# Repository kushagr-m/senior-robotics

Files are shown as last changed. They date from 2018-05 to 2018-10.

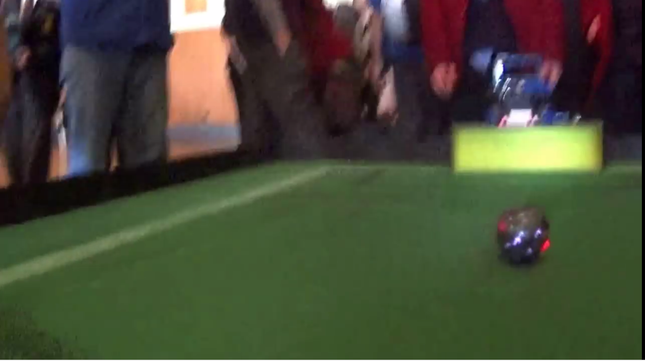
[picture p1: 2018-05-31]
callibyellow.png

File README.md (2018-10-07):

# Nationals
## Roles and Responsibilities:
- **John:** Schematic design, wiring, compass
- **Elvis:** CAD, hardware construction
- **Leon:** Component digitisation, hardware construction, strategy
- **Ben:** Hardware construction, component digitisation
- **Angus:** PCB design, serial communication, strategy
- **Kush:** OpenCV

## Timeline and Plan:
- Work out new plate designs _(Weeks 1-2) (13/08 - 26/08)_
- Work out new components, order and create schematic and PCB _(Weeks 1-4) (13/08 - 01/09)_
- Begin testing of tactics (hardware + software) _(Weeks 2-5) (20/08 - 10/09)_
- Construct robots, test, and finalise _(Weeks 4-7) (03/09 - 30/09)_
- Final optimisation _(Weeks 7-8) (24/09 - 07/10)_
- _2018 Australian Open National Competition: Sat 06/10 - Sun 07/10_

## Competition Times
### Saturday 06/10
- 11:10 Table 12 vs Legolas (Camden Haven High School) - _DRAW (0-0)_
- 12:10 Table 11 vs InfraReady (Private entry) - _LOSS (0-10)_
- 2:10 Table 12 vs Undecided (Camden Haven High School) - _DRAW (0-0)_
- 3:50 Table 12 vs Ambusch (Camden Haven High School) - _LOSS (0-?)_
### Sunday 07/10
- 10:00 Table 12 vs H010n0m1c (Private entry) - _LOSS (0-10)_
- 11:00 Table 12 vs M108 (The Scots College) - _LOSS (1-11)_
- 11:40 Table 12 vs Team APEX (Brisbane Boys College) - _LOSS (0-10)_

## Links
- **[VS Code](https://www.google.com)**: Live collaboration of code for Raspberry Pi and Arduino
- **[Upverter](https://upverter.com/Phobots/f1d2b6a10bcaeffc/Soccer-Bot/)**: Live collaboration of schematic and PCB designs

A note from our sponsors: _Congratulations on being runner up in the state competition, and now entering the national robotics competition!_

A second note from our sponsors: _Thanks for participating, here's a participation reward lmao 💩_

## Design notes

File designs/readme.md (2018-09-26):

## Design Parts ##

**DXF files:**
  - Top Plate
  - Middle Plate
  - Bottom Plate
  - Test screw

**STL files:**
 - Original Designs:
    - Outer Motor mount
    - Innter Motor mounts
    - Camera Mount
    - Dribbler Mount
    
 - Existing Designs used:
    - Wheel Mount
    - Battery Mount

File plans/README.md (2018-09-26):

# National Competition Plans
Please find plans for
- Components
- Schematic and PCB design
- Plate designs
- Other stuff

Please note that Compass Calibration Data values only for T10 at MHS!

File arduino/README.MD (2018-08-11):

# SENDING MOTOR COMMANDS

To communicate with a specific motor: `DIRECTIONspeed`

**for example:**  
`a100` (FL motor at 100% power)  
`b-100` (FR motor at -100% power)

# RECIEVING TOF DATA

TOF: `ToFNumber:Distance`

**for example:**  
`1:234` - ToF sensor 1 measures 234mm

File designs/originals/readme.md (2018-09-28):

## Original Files ##
*The files in here are all the design files in their original format (3D Models in blender, dxf designs in fusion)*
**Files in here:**
- Blender Files (3D Models):
  - Outer Mount
  - Inner Mount
  - Camera Mount
  - Dribbler
  - Visualisation (Bot in 3D)
- Fusion Files (DXF Files):
  - TopPlate
  - MidPlate
  - BotPlate
  - test (Screw holes)

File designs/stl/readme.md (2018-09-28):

## 3D Printable STL files ##

**Files:**
  - Created by Elvis:
    - Outer Mount
    - Inner Mount
    - Camera Mount
    - Dribbler Mount
  - Existing designs:
    - Wheel Mount
    - Battery Mount

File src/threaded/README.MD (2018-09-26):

# VisionProcess
Runs ball detection vision code in its own thread.  
Based on the threading implementation of `imutils`.

# Usage:
```python
from path.to.vision import VisionProcess
vp = VisionProcess().start()

While True: # in the loop
	try: 
		ret, current, queue = vp.read()
		circleCenter, circleRadius = vp.minEnclosing()
		# ...
		# write all code here.
		# ...
	
	except KeyboardInterrupt:
		break

vp.stop()

```
---

## Values:

### `ret`
Is the ball detected?  
Outputs = `True`/`False`  

### `current`
The **current ball position, relative to the center of the frame**   
Outputs = `(x,y)` (is a tuple)  
*x* = `[-160,160]`  
*y* = `[-120,120]`

### `queue`
History of all ball positions  
Outputs a queue.

---

### **NOTE:** The following two values should not be considered reliable.

### `circleCenter`
The **centre of a circle surrounding the ball**   
Outputs = `(x,y)` (is a tuple) 

### `circleRadius`
The **radius of a circle surrounding the ball**  
Outputs a **float**.

---

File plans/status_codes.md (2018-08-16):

## Status Codes of the RGB LEDs on the Raspberry Pi
### Raspberry Pi
- **Red:**
- **Green:**
- **Blue:**
- **Yellow (RG):**
- **Cyan (GB):**
- **Magenta (RB):**
- **White (RGB):**

Note: _If required, we can install another RGB LED for more combinations_

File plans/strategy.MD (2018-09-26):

# Strategy
```
If Ball is in frame 
	If goal is in front *compass*              (45˚ acceptance each side)
	Correct angle to center the ball in frame	
	move forward
		If goal is out of 45˚ acceptance
		Rotate around the ball until goal is in acceptance range
		then forward
	Else
		Move Forward+Right for 1 second
		Turn 90 degrees clockwise
		Move in a counter-clockwise direction 90 degrees around the ball
		Turn 90 degrees clockwise
Else
	Move forward+left for 0.5 seconds
	Rotate counterclockwise 1 revolution
	Move forward+right for 0.5 seconds
	Rotate counterclockwise 1 revolution
	Move backward+right for 0.5 seconds
	Rotate counterclockwise 1 revolution
	Move backward+left for 0.5 seconds
	Rotate counterclockwise 1 revolution

Note:
Revolution and rotation can be approximated through trial and error
```

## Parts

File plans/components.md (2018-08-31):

## Components
- [x] **Raspberry Pi 2 Model B+:** The brains for OpenCV and logic
  - [ ] **Raspberry Pi Camera Board 2:** To see
  - [x] **HMC5883 Digital Compass:** To find angle to goal, communicates over i2c
  - [x] **VL53L0X Time of Flight Sensors:** 4x, to find distance to edges, communicates over i2c
  - [ ] **Momentary Switch:** To detect when ball is in contact with robot when out of camera view
  - [x] **SPST Switch:** To turn off robot, or at least pause the code
  - [x] **Keyes KY-016 3-color LED module:** 2x, for visual status codes (see `/plans/status_codes`)
- [x] **Arduino MEGA R3 2560**: Generates PWM signals to control motor drivers, communicates over serial
  - [x] **L298N Dual H-Bridge Motor Driver:** 2x, uses PWM signals to control voltage to motors, has on board 5V regulator
    - [x] **6V 294RPM Motors:** 4x, To move the robot
    - [ ] **42mm Omdirectional Wheels:** 4x, to enable omnidirectional movement
- [x] **Logic Level Converter:** Enables bidirectional communication over serial, converts 5V and 3.3V into each other for Arduino and Raspberry Pi
- [x] **5V Converter:** Converts battery voltage to stable 5V to power Raspberry Pi
- [x] **Zippy 5000 20C Li-Po Battery 7.4V:** Powers everything

- [ ] **Breadboard:** To connect all i2c devices (if PCB plate cannot)

Note: _Checkboxes are currently being used for schematic component availability purposes_

----
## Schematic and PCB design
_See `/plans` for link to Upverter project, final schematic and PCB designs uploaded when complete_

----
## Other
- Print PCB as plates
- Have a way to turn on and off the robot without a computer
- Have status codes with RGB LEDs (what it is currently doing, errors...)
- Do not have plates in red or colour similar to ball

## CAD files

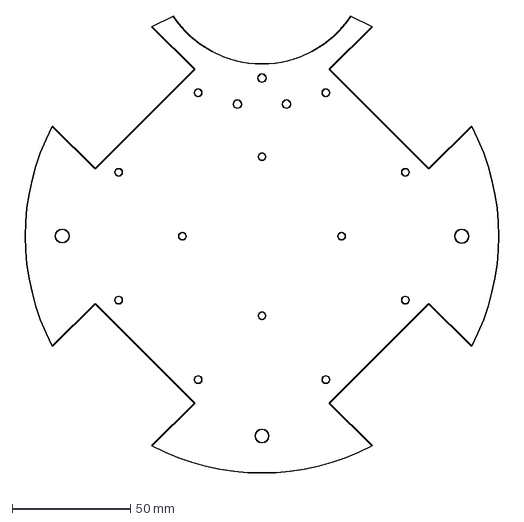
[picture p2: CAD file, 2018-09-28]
designs/dxf/BotPlate.dxf
207.6 x 196.8 mm

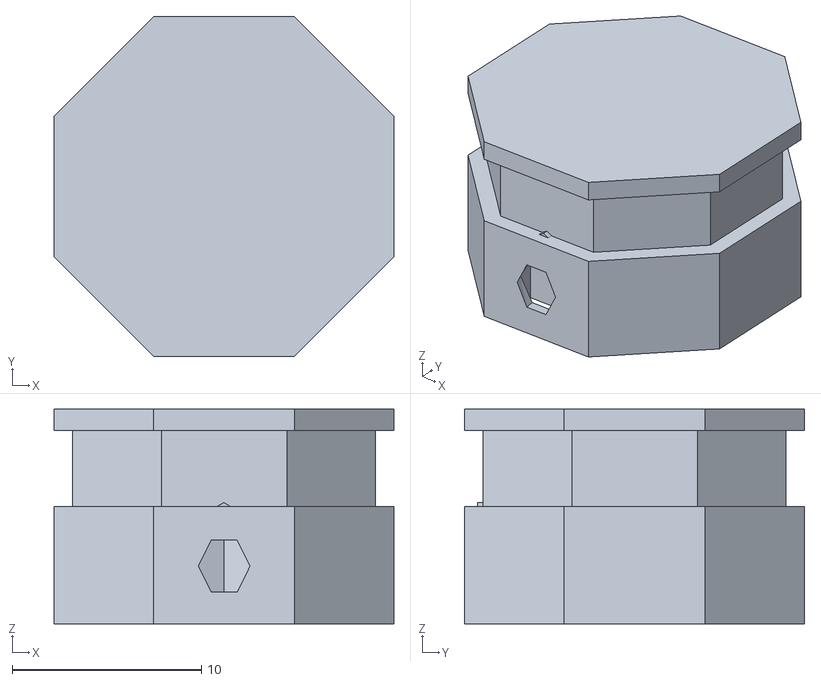
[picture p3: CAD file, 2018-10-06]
designs/stl/DribMotMount.stl
18.0 x 18.0 x 11.4

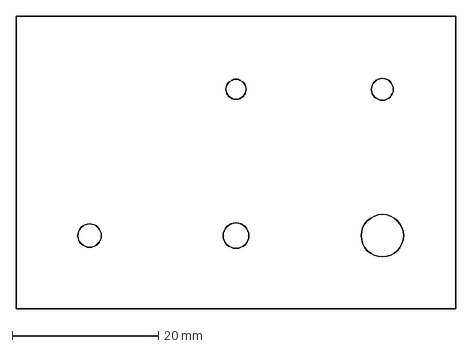
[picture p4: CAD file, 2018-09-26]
designs/dxf/test.dxf
60.0 x 40.0 mm

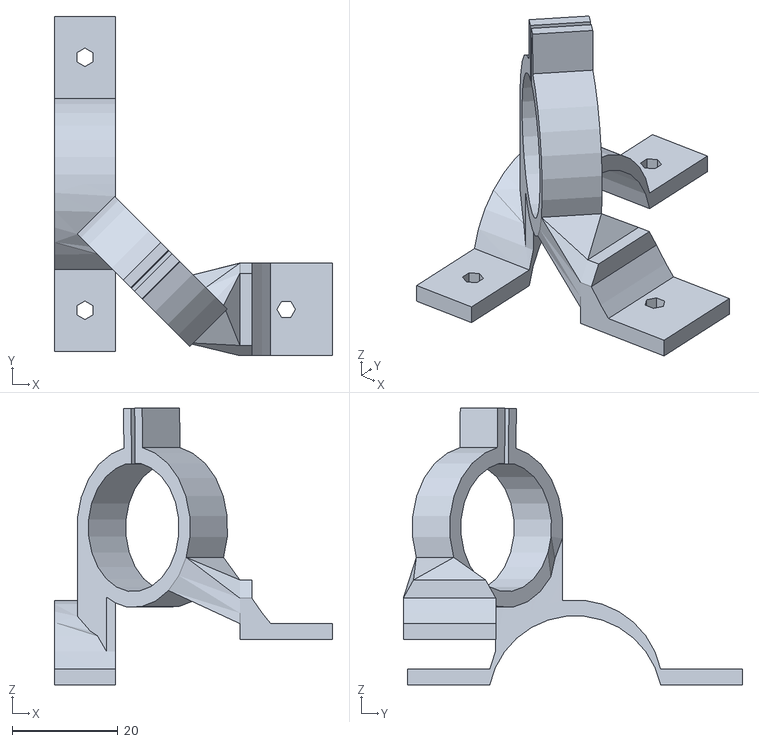
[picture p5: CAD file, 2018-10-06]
designs/stl/Motdrib1.stl
52.5 x 64.1 x 52.3

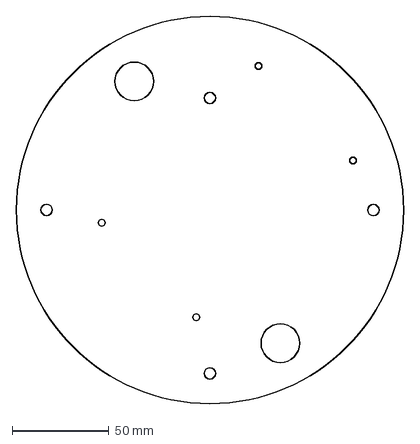
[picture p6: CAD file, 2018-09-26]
designs/dxf/TopPlate.dxf
200.0 x 200.0 mm

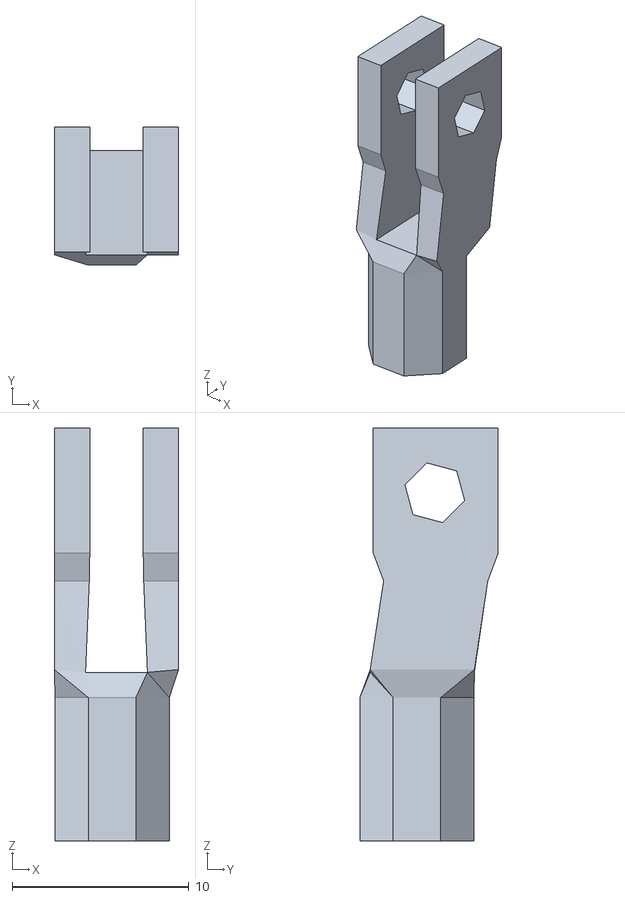
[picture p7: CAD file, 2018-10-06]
designs/stl/RollMount.stl
7.03 x 7.84 x 23.4

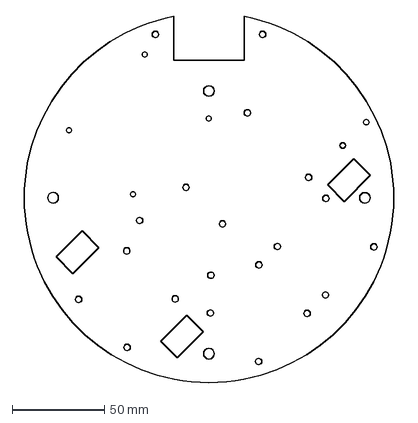
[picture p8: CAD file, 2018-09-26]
designs/dxf/MidPlate.dxf
208.9 x 198.2 mm

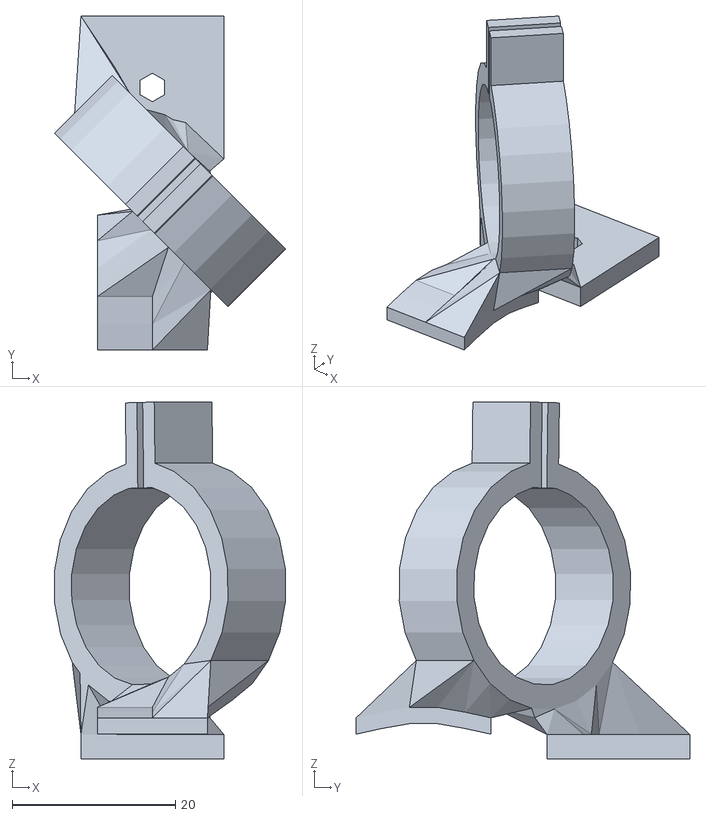
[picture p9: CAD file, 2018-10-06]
designs/stl/Motdrib2.stl
28.3 x 40.9 x 43.7

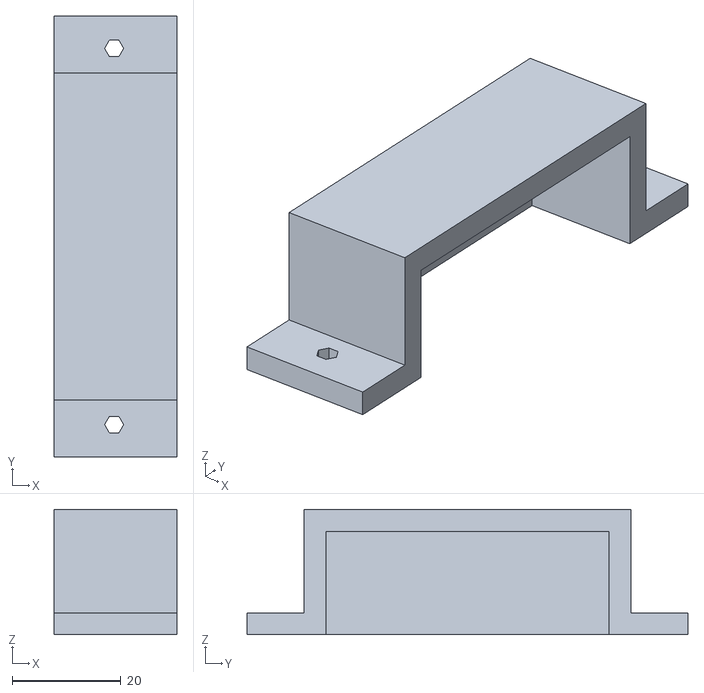
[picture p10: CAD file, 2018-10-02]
designs/stl/BatteryMountPart2.stl
22.5 x 81.0 x 23.0

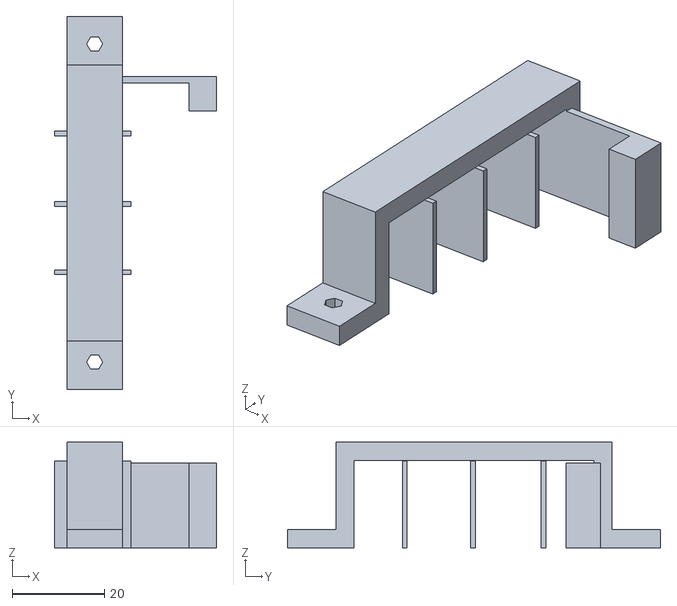
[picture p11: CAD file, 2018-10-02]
designs/stl/BatteryMountPart1.stl
35.2 x 81.0 x 23.0

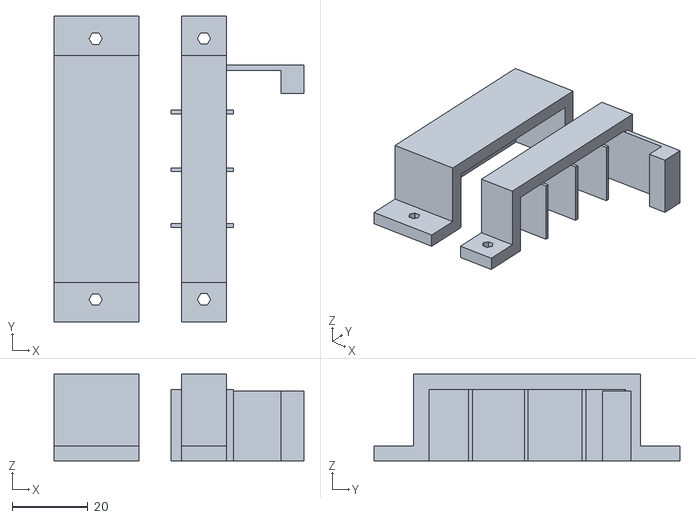
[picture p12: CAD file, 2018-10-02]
designs/stl/BatteryMount.stl
66.1 x 81.0 x 23.0

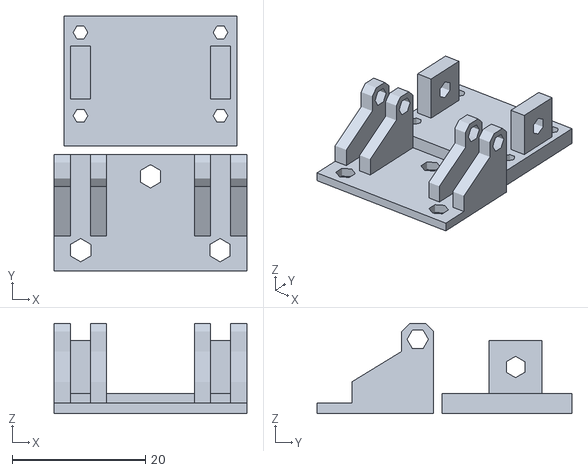
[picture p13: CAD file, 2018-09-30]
designs/stl/CameraMount.stl
28.9 x 38.2 x 13.5

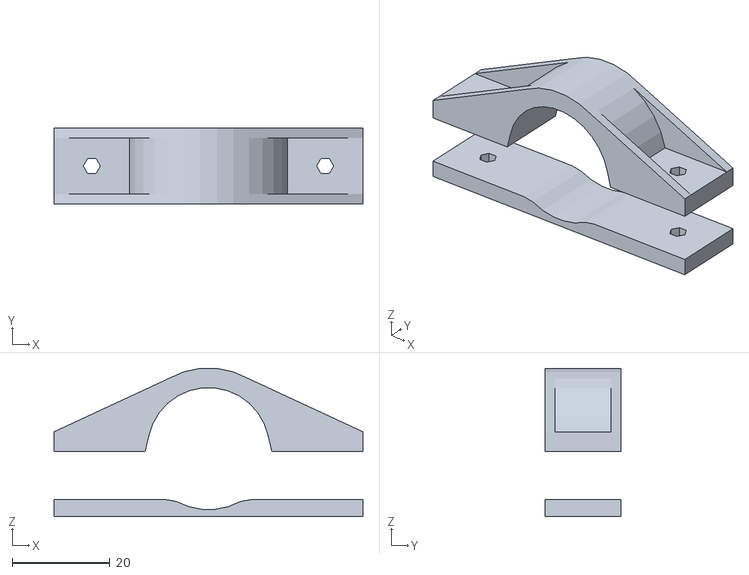
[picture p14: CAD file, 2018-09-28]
designs/stl/OuterMount.stl
63.3 x 15.5 x 30.4

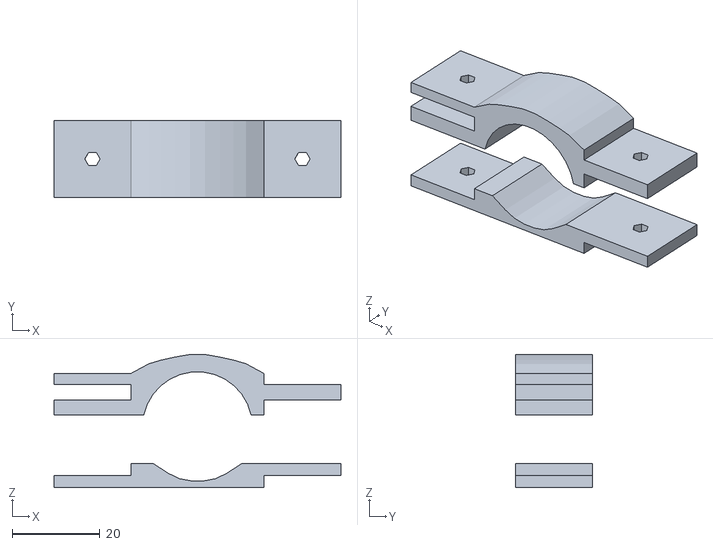
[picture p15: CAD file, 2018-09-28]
designs/stl/InnerMount.stl
65.3 x 17.5 x 30.3

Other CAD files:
designs/stl/WheelMount.stl
designs/originals/Blender Files/Bot Visualisation.blend
designs/originals/Blender Files/Camera Mount.blend
designs/originals/Blender Files/Inner Mount.blend
designs/originals/Blender Files/Outer Mount.blend
designs/originals/Fusion Files/BotPlate.f3d
designs/originals/Fusion Files/MidPlate.f3d
designs/originals/Fusion Files/TopPlate.f3d
designs/originals/Fusion Files/test.f3d

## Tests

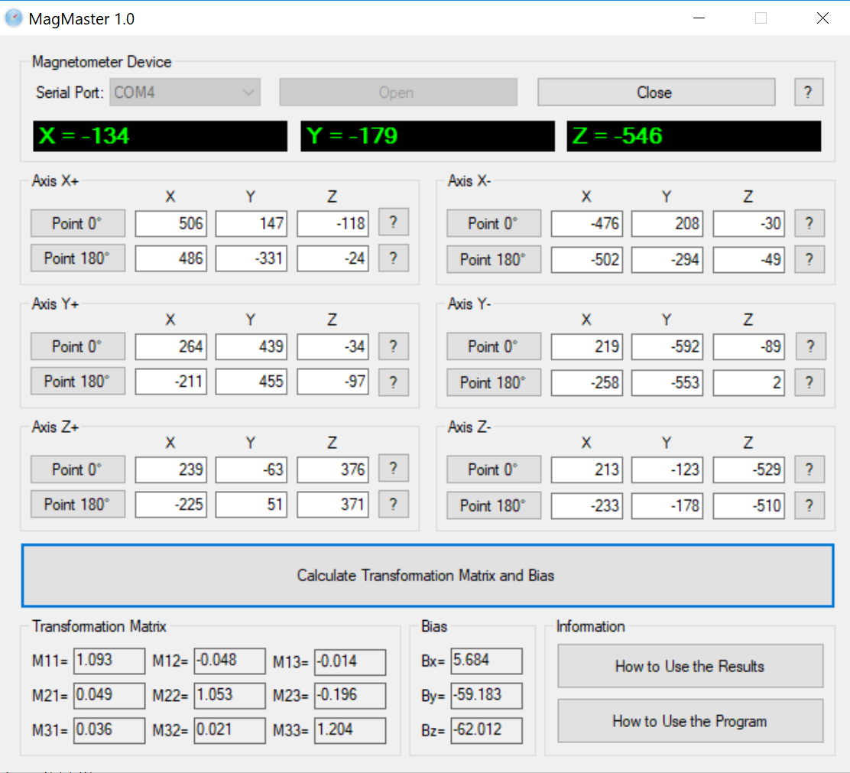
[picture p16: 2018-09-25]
plans/Compass Calibration.png

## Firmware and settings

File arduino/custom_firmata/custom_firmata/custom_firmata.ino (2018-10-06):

/*
  Firmata is a generic protocol for communicating with microcontrollers
  from software on a host computer. It is intended to work with
  any host computer software package.

  To download a host software package, please click on the following link
  to open the list of Firmata client libraries in your default browser.

  https://github.com/firmata/arduino#firmata-client-libraries

  Copyright (C) 2006-2008 Hans-Christoph Steiner.  All rights reserved.
  Copyright (C) 2010-2011 Paul Stoffregen.  All rights reserved.
  Copyright (C) 2009 Shigeru Kobayashi.  All rights reserved.
  Copyright (C) 2009-2016 Jeff Hoefs.  All rights reserved.

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
  See file LICENSE.txt for further informations on licensing terms.

  Last updated August 17th, 2017
*/

#include <Firmata.h>
#include <Adafruit_Sensor.h>
#include <Adafruit_HMC5883_U.h>
#include <Adafruit_SSD1306.h>
#include <Adafruit_GFX.h>

// the minimum interval for sampling analog input
#define MINIMUM_SAMPLING_INTERVAL   1
#define OLED_ADDR   0x3C

Adafruit_SSD1306 display(-1);

#if (SSD1306_LCDHEIGHT != 64)
#error("Height incorrect, please fix Adafruit_SSD1306.h!");
#endif

/*==============================================================================
   GLOBAL VARIABLES
  ============================================================================*/

Adafruit_HMC5883_Unified mag = Adafruit_HMC5883_Unified(12345);

int compass_read()
{
  sensors_event_t event;
  mag.getEvent(&event);
  float heading = atan2(event.magnetic.y, event.magnetic.x);
  float declinationAngle = 0.202749081;
  heading += declinationAngle;
  if (heading < 0)
    heading += 2 * PI;
  if (heading > 2 * PI)
    heading -= 2 * PI;
  float headingDegrees = heading * 180 / M_PI;
  return (int)headingDegrees;
}

#ifdef FIRMATA_SERIAL_FEATURE
SerialFirmata serialFeature;
#endif

/* analog inputs */
int analogInputsToReport = 0; // bitwise array to store pin reporting

/* digital input ports */
byte reportPINs[TOTAL_PORTS];       // 1 = report this port, 0 = silence
byte previousPINs[TOTAL_PORTS];     // previous 8 bits sent

/* pins configuration */
byte portConfigInputs[TOTAL_PORTS]; // each bit: 1 = pin in INPUT, 0 = anything else

/* timer variables */
unsigned long currentMillis;        // store the current value from millis()
unsigned long previousMillis;       // for comparison with currentMillis
unsigned int samplingInterval = 19; // how often to run the main loop (in ms)

boolean isResetting = false;

// Forward declare a few functions to avoid compiler errors with older versions
// of the Arduino IDE.
void setPinModeCallback(byte, int);
void reportAnalogCallback(byte analogPin, int value);
void sysexCallback(byte, byte, byte*);

void outputPort(byte portNumber, byte portValue, byte forceSend)
{
  // pins not configured as INPUT are cleared to zeros
  portValue = portValue & portConfigInputs[portNumber];
  // only send if the value is different than previously sent
  if (forceSend || previousPINs[portNumber] != portValue) {
    Firmata.sendDigitalPort(portNumber, portValue);
    previousPINs[portNumber] = portValue;
  }
}

/* -----------------------------------------------------------------------------
   check all the active digital inputs for change of state, then add any events
   to the Serial output queue using Serial.print() */
void checkDigitalInputs(void)
{
  /* Using non-looping code allows constants to be given to readPort().
     The compiler will apply substantial optimizations if the inputs
     to readPort() are compile-time constants. */
  if (TOTAL_PORTS > 0 && reportPINs[0]) outputPort(0, readPort(0, portConfigInputs[0]), false);
  if (TOTAL_PORTS > 1 && reportPINs[1]) outputPort(1, readPort(1, portConfigInputs[1]), false);
  if (TOTAL_PORTS > 2 && reportPINs[2]) outputPort(2, readPort(2, portConfigInputs[2]), false);
  if (TOTAL_PORTS > 3 && reportPINs[3]) outputPort(3, readPort(3, portConfigInputs[3]), false);
  if (TOTAL_PORTS > 4 && reportPINs[4]) outputPort(4, readPort(4, portConfigInputs[4]), false);
  if (TOTAL_PORTS > 5 && reportPINs[5]) outputPort(5, readPort(5, portConfigInputs[5]), false);
  if (TOTAL_PORTS > 6 && reportPINs[6]) outputPort(6, readPort(6, portConfigInputs[6]), false);
  if (TOTAL_PORTS > 7 && reportPINs[7]) outputPort(7, readPort(7, portConfigInputs[7]), false);
  if (TOTAL_PORTS > 8 && reportPINs[8]) outputPort(8, readPort(8, portConfigInputs[8]), false);
  if (TOTAL_PORTS > 9 && reportPINs[9]) outputPort(9, readPort(9, portConfigInputs[9]), false);
  if (TOTAL_PORTS > 10 && reportPINs[10]) outputPort(10, readPort(10, portConfigInputs[10]), false);
  if (TOTAL_PORTS > 11 && reportPINs[11]) outputPort(11, readPort(11, portConfigInputs[11]), false);
  if (TOTAL_PORTS > 12 && reportPINs[12]) outputPort(12, readPort(12, portConfigInputs[12]), false);
  if (TOTAL_PORTS > 13 && reportPINs[13]) outputPort(13, readPort(13, portConfigInputs[13]), false);
  if (TOTAL_PORTS > 14 && reportPINs[14]) outputPort(14, readPort(14, portConfigInputs[14]), false);
  if (TOTAL_PORTS > 15 && reportPINs[15]) outputPort(15, readPort(15, portConfigInputs[15]), false);
}

// -----------------------------------------------------------------------------
/* sets the pin mode to the correct state and sets the relevant bits in the
   two bit-arrays that track Digital I/O and PWM status
*/
void setPinModeCallback(byte pin, int mode)
{
  if (Firmata.getPinMode(pin) == PIN_MODE_IGNORE)
    return;

  if (IS_PIN_ANALOG(pin)) {
    reportAnalogCallback(PIN_TO_ANALOG(pin), mode == PIN_MODE_ANALOG ? 1 : 0); // turn on/off reporting
  }
  if (IS_PIN_DIGITAL(pin)) {
    if (mode == INPUT || mode == PIN_MODE_PULLUP) {
      portConfigInputs[pin / 8] |= (1 << (pin & 7));
    } else {
      portConfigInputs[pin / 8] &= ~(1 << (pin & 7));
    }
  }
  Firmata.setPinState(pin, 0);
  switch (mode) {
    case PIN_MODE_ANALOG:
      if (IS_PIN_ANALOG(pin)) {
        if (IS_PIN_DIGITAL(pin)) {
          pinMode(PIN_TO_DIGITAL(pin), INPUT);    // disable output driver
#if ARDUINO <= 100
          // deprecated since Arduino 1.0.1 - TODO: drop support in Firmata 2.6
          digitalWrite(PIN_TO_DIGITAL(pin), LOW); // disable internal pull-ups
#endif
        }
        Firmata.setPinMode(pin, PIN_MODE_ANALOG);
      }
      break;
    case INPUT:
      if (IS_PIN_DIGITAL(pin)) {
        pinMode(PIN_TO_DIGITAL(pin), INPUT);    // disable output driver
#if ARDUINO <= 100
        // deprecated since Arduino 1.0.1 - TODO: drop support in Firmata 2.6
        digitalWrite(PIN_TO_DIGITAL(pin), LOW); // disable internal pull-ups
#endif
        Firmata.setPinMode(pin, INPUT);
      }
      break;
    case PIN_MODE_PULLUP:
      if (IS_PIN_DIGITAL(pin)) {
        pinMode(PIN_TO_DIGITAL(pin), INPUT_PULLUP);
        Firmata.setPinMode(pin, PIN_MODE_PULLUP);
        Firmata.setPinState(pin, 1);
      }
      break;
    case OUTPUT:
      if (IS_PIN_DIGITAL(pin)) {
        if (Firmata.getPinMode(pin) == PIN_MODE_PWM) {
          // Disable PWM if pin mode was previously set to PWM.
          digitalWrite(PIN_TO_DIGITAL(pin), LOW);
        }
        pinMode(PIN_TO_DIGITAL(pin), OUTPUT);
        Firmata.setPinMode(pin, OUTPUT);
      }
      break;
    case PIN_MODE_PWM:
      if (IS_PIN_PWM(pin)) {
        pinMode(PIN_TO_PWM(pin), OUTPUT);
        analogWrite(PIN_TO_PWM(pin), 0);
        Firmata.setPinMode(pin, PIN_MODE_PWM);
      }
      break;
    case PIN_MODE_SERIAL:
#ifdef FIRMATA_SERIAL_FEATURE
      serialFeature.handlePinMode(pin, PIN_MODE_SERIAL);
#endif
      break;
    default:
      Firmata.sendString("Unknown pin mode"); // TODO: put error msgs in EEPROM
  }
  // TODO: save status to EEPROM here, if changed
}

/*
   Sets the value of an individual pin. Useful if you want to set a pin value but
   are not tracking the digital port state.
   Can only be used on pins configured as OUTPUT.
   Cannot be used to enable pull-ups on Digital INPUT pins.
*/
void setPinValueCallback(byte pin, int value)
{
  if (pin < TOTAL_PINS && IS_PIN_DIGITAL(pin)) {
    if (Firmata.getPinMode(pin) == OUTPUT) {
      Firmata.setPinState(pin, value);
      digitalWrite(PIN_TO_DIGITAL(pin), value);
    }
  }
}

void analogWriteCallback(byte pin, int value)
{
  if (pin < TOTAL_PINS) {
    switch (Firmata.getPinMode(pin)) {
      case PIN_MODE_PWM:
        if (IS_PIN_PWM(pin))
          analogWrite(PIN_TO_PWM(pin), value);
        Firmata.setPinState(pin, value);
        break;
    }
  }
}

void digitalWriteCallback(byte port, int value)
{
  byte pin, lastPin, pinValue, mask = 1, pinWriteMask = 0;

  if (port < TOTAL_PORTS) {
    // create a mask of the pins on this port that are writable.
    lastPin = port * 8 + 8;
    if (lastPin > TOTAL_PINS) lastPin = TOTAL_PINS;
    for (pin = port * 8; pin < lastPin; pin++) {
      // do not disturb non-digital pins (eg, Rx & Tx)
      if (IS_PIN_DIGITAL(pin)) {
        // do not touch pins in PWM, ANALOG, SERVO or other modes
        if (Firmata.getPinMode(pin) == OUTPUT || Firmata.getPinMode(pin) == INPUT) {
          pinValue = ((byte)value & mask) ? 1 : 0;
          if (Firmata.getPinMode(pin) == OUTPUT) {
            pinWriteMask |= mask;
          } else if (Firmata.getPinMode(pin) == INPUT && pinValue == 1 && Firmata.getPinState(pin) != 1) {
            // only handle INPUT here for backwards compatibility
#if ARDUINO > 100
            pinMode(pin, INPUT_PULLUP);
#else
            // only write to the INPUT pin to enable pullups if Arduino v1.0.0 or earlier
            pinWriteMask |= mask;
#endif
          }
          Firmata.setPinState(pin, pinValue);
        }
      }
      mask = mask << 1;
    }
    writePort(port, (byte)value, pinWriteMask);
  }
}


// -----------------------------------------------------------------------------
/* sets bits in a bit array (int) to toggle the reporting of the analogIns
*/
//void FirmataClass::setAnalogPinReporting(byte pin, byte state) {
//}
void reportAnalogCallback(byte analogPin, int value)
{
  if (analogPin < TOTAL_ANALOG_PINS) {
    if (value == 0) {
      analogInputsToReport = analogInputsToReport & ~ (1 << analogPin);
    } else {
      analogInputsToReport = analogInputsToReport | (1 << analogPin);
      // prevent during system reset or all analog pin values will be reported
      // which may report noise for unconnected analog pins
      if (!isResetting) {
        // Send pin value immediately. This is helpful when connected via
        // ethernet, wi-fi or bluetooth so pin states can be known upon
        // reconnecting.
        Firmata.sendAnalog(analogPin, compass_read());
      }
    }
  }
  // TODO: save status to EEPROM here, if changed
}

void reportDigitalCallback(byte port, int value)
{
  if (port < TOTAL_PORTS) {
    reportPINs[port] = (byte)value;
    // Send port value immediately. This is helpful when connected via
    // ethernet, wi-fi or bluetooth so pin states can be known upon
    // reconnecting.
    if (value) outputPort(port, readPort(port, portConfigInputs[port]), true);
  }
  // do not disable analog reporting on these 8 pins, to allow some
  // pins used for digital, others analog.  Instead, allow both types
  // of reporting to be enabled, but check if the pin is configured
  // as analog when sampling the analog inputs.  Likewise, while
  // scanning digital pins, portConfigInputs will mask off values from any
  // pins configured as analog
}

/*==============================================================================
   SYSEX-BASED commands
  ============================================================================*/

void sysexCallback(byte command, byte argc, byte *argv)
{
  byte mode;
  byte stopTX;
  byte slaveAddress;
  byte data;
  int slaveRegister;
  unsigned int delayTime;

  switch (command) {
    case SAMPLING_INTERVAL:
      if (argc > 1) {
        samplingInterval = argv[0] + (argv[1] << 7);
        if (samplingInterval < MINIMUM_SAMPLING_INTERVAL) {
          samplingInterval = MINIMUM_SAMPLING_INTERVAL;
        }
      } else {
        //Firmata.sendString("Not enough data");
      }
      break;
    case EXTENDED_ANALOG:
      if (argc > 1) {
        int val = argv[1];
        if (argc > 2) val |= (argv[2] << 7);
        if (argc > 3) val |= (argv[3] << 14);
        analogWriteCallback(argv[0], val);
      }
      break;
    case CAPABILITY_QUERY:
      Firmata.write(START_SYSEX);
      Firmata.write(CAPABILITY_RESPONSE);
      for (byte pin = 0; pin < TOTAL_PINS; pin++) {
        if (IS_PIN_DIGITAL(pin)) {
          Firmata.write((byte)INPUT);
          Firmata.write(1);
          Firmata.write((byte)PIN_MODE_PULLUP);
          Firmata.write(1);
          Firmata.write((byte)OUTPUT);
          Firmata.write(1);
        }
        if (IS_PIN_ANALOG(pin)) {
          Firmata.write(PIN_MODE_ANALOG);
          Firmata.write(10); // 10 = 10-bit resolution
        }
        if (IS_PIN_PWM(pin)) {
          Firmata.write(PIN_MODE_PWM);
          Firmata.write(DEFAULT_PWM_RESOLUTION);
        }
#ifdef FIRMATA_SERIAL_FEATURE
        serialFeature.handleCapability(pin);
#endif
        Firmata.write(127);
      }
      Firmata.write(END_SYSEX);
      break;
    case PIN_STATE_QUERY:
      if (argc > 0) {
        byte pin = argv[0];
        Firmata.write(START_SYSEX);
        Firmata.write(PIN_STATE_RESPONSE);
        Firmata.write(pin);
        if (pin < TOTAL_PINS) {
          Firmata.write(Firmata.getPinMode(pin));
          Firmata.write((byte)Firmata.getPinState(pin) & 0x7F);
          if (Firmata.getPinState(pin) & 0xFF80) Firmata.write((byte)(Firmata.getPinState(pin) >> 7) & 0x7F);
          if (Firmata.getPinState(pin) & 0xC000) Firmata.write((byte)(Firmata.getPinState(pin) >> 14) & 0x7F);
        }
        Firmata.write(END_SYSEX);
      }
      break;
    case ANALOG_MAPPING_QUERY:
      Firmata.write(START_SYSEX);
      Firmata.write(ANALOG_MAPPING_RESPONSE);
      for (byte pin = 0; pin < TOTAL_PINS; pin++) {
        Firmata.write(IS_PIN_ANALOG(pin) ? PIN_TO_ANALOG(pin) : 127);
      }
      Firmata.write(END_SYSEX);
      break;

    case SERIAL_MESSAGE:
#ifdef FIRMATA_SERIAL_FEATURE
      serialFeature.handleSysex(command, argc, argv);
#endif
      break;
  }
}

/*==============================================================================
   SETUP()
  ============================================================================*/

void systemResetCallback()
{
  isResetting = true;

  // initialize a defalt state
  // TODO: option to load config from EEPROM instead of default

#ifdef FIRMATA_SERIAL_FEATURE
  serialFeature.reset();
#endif

  for (byte i = 0; i < TOTAL_PORTS; i++) {
    reportPINs[i] = false;    // by default, reporting off
    portConfigInputs[i] = 0;  // until activated
    previousPINs[i] = 0;
  }

  for (byte i = 0; i < TOTAL_PINS; i++) {
    // pins with analog capability default to analog input
    // otherwise, pins default to digital output
    if (IS_PIN_ANALOG(i)) {
      // turns off pullup, configures everything
      setPinModeCallback(i, PIN_MODE_ANALOG);
    } else if (IS_PIN_DIGITAL(i)) {
      // sets the output to 0, configures portConfigInputs
      setPinModeCallback(i, OUTPUT);
    }
  }
  // by default, do not report any analog inputs
  analogInputsToReport = 0;

  /* send digital inputs to set the initial state on the host computer,
     since once in the loop(), this firmware will only send on change */
  /*
    TODO: this can never execute, since no pins default to digital input
        but it will be needed when/if we support EEPROM stored config
    for (byte i=0; i < TOTAL_PORTS; i++) {
    outputPort(i, readPort(i, portConfigInputs[i]), true);
    }
  */
  isResetting = false;
}

void setup()
{
  // initialize and clear display
  display.begin(SSD1306_SWITCHCAPVCC, OLED_ADDR);
  display.clearDisplay();
  display.display();

  // display a pixel in each corner of the screen
  display.drawPixel(0, 0, WHITE);
  display.drawPixel(127, 0, WHITE);
  display.drawPixel(0, 63, WHITE);
  display.drawPixel(127, 63, WHITE);

  // display a line of text
  display.setTextSize(1);
  display.setTextColor(WHITE);
  display.setCursor(1, 30);
  display.print("Initialising...");

  // update display with all of the above graphics
  display.display();

  Firmata.setFirmwareVersion(FIRMATA_FIRMWARE_MAJOR_VERSION, FIRMATA_FIRMWARE_MINOR_VERSION);

  Firmata.attach(ANALOG_MESSAGE, analogWriteCallback);
  Firmata.attach(DIGITAL_MESSAGE, digitalWriteCallback);
  Firmata.attach(REPORT_ANALOG, reportAnalogCallback);
  Firmata.attach(REPORT_DIGITAL, reportDigitalCallback);
  Firmata.attach(SET_PIN_MODE, setPinModeCallback);
  Firmata.attach(SET_DIGITAL_PIN_VALUE, setPinValueCallback);
  Firmata.attach(START_SYSEX, sysexCallback);
  Firmata.attach(SYSTEM_RESET, systemResetCallback);

  // to use a port other than Serial, such as Serial1 on an Arduino Leonardo or Mega,
  // Call begin(baud) on the alternate serial port and pass it to Firmata to begin like this:
  // Serial1.begin(57600);
  // Firmata.begin(Serial1);
  // However do not do this if you are using SERIAL_MESSAGE

  Firmata.begin(57600);
  while (!Serial) {
    ; // wait for serial port to connect. Needed for ATmega32u4-based boards and Arduino 101
  }

  systemResetCallback();  // reset to default config

  mag.begin();

  delay(500);
  display.clearDisplay();
}

/*==============================================================================
   LOOP()
  ============================================================================*/
void loop()
{
  byte pin, analogPin;

  /* DIGITALREAD - as fast as possible, check for changes and output them to the
     FTDI buffer using Serial.print()  */
  checkDigitalInputs();

  /* STREAMREAD - processing incoming messagse as soon as possible, while still
     checking digital inputs.  */
  while (Firmata.available())
    Firmata.processInput();

  // TODO - ensure that Stream buffer doesn't go over 60 bytes
  currentMillis = millis();
  if (currentMillis - previousMillis > samplingInterval) {
    int compass_val = compass_read();
    previousMillis = currentMillis;
    /* ANALOGREAD - do all analogReads() at the configured sampling interval */
    for (pin = 0; pin < TOTAL_PINS; pin++) {
      if (IS_PIN_ANALOG(pin) && Firmata.getPinMode(pin) == PIN_MODE_ANALOG) {
        analogPin = PIN_TO_ANALOG(pin);
        if (analogInputsToReport & (1 << analogPin)) {
          // Firmata.sendAnalog(analogPin, analogRead(analogPin));
          Firmata.sendAnalog(analogPin, compass_val);
        }
      }
    }
    display.clearDisplay();
    display.setTextSize(1);
    display.setTextColor(WHITE);
    display.setCursor(1, 30);
    display.print("Bearing: ");
    display.print(compass_val);
    display.display();
  }


#ifdef FIRMATA_SERIAL_FEATURE
  serialFeature.update();
#endif
}

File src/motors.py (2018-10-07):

import math
from pymata_aio.pymata3 import PyMata3
from pymata_aio.constants import Constants as PyMataConstants

# Motor pins
motors = [
    (5, 4), # FL
    (3, 2), # FR
    (10, 9), # BL
    (12, 11), # BR
    (6, 7) # Dribbler
]

current_power = [ 0, 0, 0, 0, 0 ]

board = PyMata3(com_port="/dev/ttyS0")
# board = PyMata3()

# Set up motor output pins
for motor in motors:
    board.set_pin_mode(motor[0], PyMataConstants.PWM)
    board.set_pin_mode(motor[1], PyMataConstants.PWM)

def set_motor(motor, power = 100):
    if current_power[motor] != power:
        current_power[motor] = power
        scaled_power = math.floor(abs(power) * 2.55)
        print("Set motor ", motor, scaled_power)

        if power > 0:
            board.analog_write(motors[motor][0], scaled_power)
            board.analog_write(motors[motor][1], 0)
        else:
            board.analog_write(motors[motor][0], 0)
            board.analog_write(motors[motor][1], scaled_power)

def FL(power):
    set_motor(0, power)

def FR(power):
    set_motor(1, power)

def BL(power):
    set_motor(2, power)

def BR(power):
    set_motor(3, power)

def Dribbler(power):
    set_motor(4, power)

def stop():
    FL(0)
    FR(0)
    BR(0)
    BL(0)
    Dribbler(0)

def goStraight(power = 100):
    FR(power)
    FL(-1*power)
    BR(power)
    #BR(0)
    BL(-1*power)
    #BL(0)

def goLeft(power = 100):
    FR(power)
    #FR(0)
    FL(power)
    BR(-1*power)
    #BR(0)
    BL(-1*power)

def goRight(power = 100):
    FR(-1*power)
    FL(-1*power)
    #FL(0)
    BR(power)
    BL(power)
    #BL(0)

def goBack(power = 100):
    FR(-1*power)
    #FR(0)
    FL(power)
    #FL(0)
    BR(-1*power)
    BL(power)

def goFR(power = 100):
    FL(-1*power)
    FR(0)
    BL(0)
    BR(power)

def goFL(power = 100):
    FL(0)
    FR(power)
    BL(-1*power)
    BR(0)

def goBR(power = 100):
    FL(0)
    FR(-1*power)
    BL(power)
    BR(0)

def goBL(power = 100):
    FL(power)
    FR(0)
    BL(0)
    BR(-1*power)

def rotateCenter(direction = -1, power = 100):
    if direction < 0:
        #FR(power)
        FR(0)
        FL(power)
        BR(power)
        #BL(power)
        BL(0)

    if direction > 0:
        #FR(-1*power)
        FR(0)
        FL(-1*power)
        BR(-1*power)
        #BL(-1*power)
        BL(0)

def rotateFrAxis(direction = -1, power = 100):
    if direction < 0:
        FR(0)
        FL(0)
        BR(-1*power)
        BL(-1*power)

    if direction > 0:
        FR(0)
        FL(0)
        BR(power)
        BL(power)
        
def reverse():
    for i in range(0, len(current_power)):
        set_motor(i, -current_power[i])


def cleanup():
    stop()

board.set_pin_mode(0, PyMataConstants.ANALOG)
def compassHeading():
    return board.analog_read(0)

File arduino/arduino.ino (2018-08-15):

/*
   en is used for analog data from 0 to 255 (but is mapped, so 0-100 over serial comms)
   in is used for digital - HIGH and LOW data, like instant h'bam... you know?
   input: DIRECTIONspeed (e.g. N100 - north wheel move at 100% power)
   output: ToFNumber:Distance (e.g. 1:234 - ToF sensor 1 measures 234mm)
*/
//#include "Adafruit_VL53L0X.h" // Created by Adafruit - library for ToF
//#include <Wire.h> // to communicate with i2c devices - remove comments when ToF installed

// board 1 motor 1
const int in11 = 12;
const int in12 = 11;
// board 1 motor 2
const int in13 = 10;
const int in14 = 9;
// board 2 motor 3
const int in21 = 5;
const int in22 = 4;
// board 2 motor 4
const int in23 = 3;
const int in24 = 2;

//// dual ToF setup (i2c address and shut down pins - to set custom address)
//#define LOX1_ADDRESS 0x30
//#define LOX2_ADDRESS 0x31
//#define SHT_LOX1 14
//#define SHT_LOX2 15
//// ToF objects
//Adafruit_VL53L0X lox1 = Adafruit_VL53L0X();
//Adafruit_VL53L0X lox2 = Adafruit_VL53L0X();
//
////Input and Output Data
//VL53L0X_RangingMeasurementData_t measure1; // ToF measurements
//VL53L0X_RangingMeasurementData_t measure2;
int flSpeed = 0; // specific motor speed (percentage) - front left, front left reverse
int flrSpeed = 0;
int frSpeed = 0;
int frrSpeed = 0;
int blSpeed = 0;
int blrSpeed = 0;
int brSpeed = 0;
int brrSpeed = 0;
String inputString = ""; // holds serial comm from rPi
String outputString = ""; // sends ToF data to rPi
boolean stringComplete = false;
int motNum;

void serialInput() {
  //Select correct motor driver and motor for control, and wheel direction (i.e. CW or ACW)
  if (Serial.available()) {
    char inChar = (char)Serial.read();

    if (inChar == 'a') // FRONT LEFT
    {
      motNum = 3;
      stringComplete = true;
    }
    else if (inChar == 'A')
    {
      motNum = 31;
      stringComplete = true;
    }
    else if (inChar == 'b') // FRONT RIGHT
    {
      motNum = 4;
      stringComplete = true;
    }
    else if (inChar == 'B')
    {
      motNum = 41;
      stringComplete = true;
    }
    else if (inChar == 'd') // BACK RIGHT
    {
      motNum = 1;
      stringComplete = true;
    }
    else if (inChar == 'D')
    {
      motNum = 11;
      stringComplete = true;
    }
    else if (inChar == 'c') // BACK LEFT
    {
      motNum = 2;
      stringComplete = true;
    }
    else if (inChar == 'C')
    {
      motNum = 21; //41
      stringComplete = true;
    }
    else if (inChar == '\n') //remove if necessary
    {
      // stringComplete = true;
      // motNum = 0;
    }
    else
    {
      inputString += inChar;
      //inputString.concat(inChar);
      Serial.print("other:");
      Serial.println(inputString);
    }
  }
}

void setID() {
  //  // all reset
  //  digitalWrite(SHT_LOX1, LOW);
  //  digitalWrite(SHT_LOX2, LOW);
  //  delay(10);
  //  // all unreset
  //  digitalWrite(SHT_LOX1, HIGH);
  //  digitalWrite(SHT_LOX2, HIGH);
  //  delay(10);
  //
  //  // activating LOX1 and reseting LOX2
  //  digitalWrite(SHT_LOX1, HIGH);
  //  digitalWrite(SHT_LOX2, LOW);
  //
  //  // initing LOX1
  //  if(!lox1.begin(LOX1_ADDRESS)) {
  //    Serial.println(F("Failed to boot first VL53L0X"));
  //    while(1);
  //  }
  //  delay(10);
  //
  //  // activating LOX2
  //  digitalWrite(SHT_LOX2, HIGH);
  //  delay(10);
  //
  //  //initing LOX2
  //  if(!lox2.begin(LOX2_ADDRESS)) {
  //    Serial.println(F("Failed to boot second VL53L0X"));
  //    while(1);
  //  }
}

void serialOutput() {
  // ToF Code
  //  lox1.rangingTest(&measure1, false); // change to 'true' to get debug data
  //  lox2.rangingTest(&measure2, false);
  //
  //  // print sensor readings
  //  Serial.print("1:");
  //  if(measure1.RangeStatus != 4) {     // if not out of range
  //    Serial.println(measure1.RangeMilliMeter);
  //  } else {
  //    Serial.println("out of range");
  //  }
  //  Serial.print("2:");
  //  if(measure2.RangeStatus != 4) {
  //    Serial.println(measure2.RangeMilliMeter);
  //  } else {
  //    Serial.println("out of range");
  //  }
}

void setup(){
  Serial.begin(115200);
  inputString.reserve(200);
  outputString.reserve(200);

  //  // wait for serial ready, shut down and reset for separate addresses
  //  while (! Serial) { delay(1); }
  //  pinMode(SHT_LOX1, OUTPUT);
  //  pinMode(SHT_LOX2, OUTPUT);
  //  digitalWrite(SHT_LOX1, LOW);
  //  digitalWrite(SHT_LOX2, LOW);
  //  setID();

  // motor driver outputs
  pinMode(in11, OUTPUT);
  pinMode(in21, OUTPUT);
  pinMode(in12, OUTPUT);
  pinMode(in22, OUTPUT);
  pinMode(in13, OUTPUT);
  pinMode(in23, OUTPUT);
  pinMode(in14, OUTPUT);
  pinMode(in24, OUTPUT);

  stringComplete = false;
}

void loop() {
  serialInput();
  if (stringComplete) {
    //Serial.print("inputstring:");
    //Serial.println(inputString);
    if (motNum == 1) {
      flSpeed = map(inputString.toInt(), 0, 100, 0, 255); //Converts 0-100 values to 0-255
      analogWrite(in11, flSpeed);
      analogWrite(in12, 0);
    }
    else if (motNum == 11) {
      flrSpeed = map(inputString.toInt(), 0, 100, 0, 255);
      analogWrite(in11, 0);
      analogWrite(in12, flrSpeed);
    }
    if (motNum == 2) {
      frSpeed = map(inputString.toInt(), 0, 100, 0, 255);
      analogWrite(in13, frSpeed);
      analogWrite(in14, 0);
    }
    else if (motNum == 21) {
      frrSpeed = map(inputString.toInt(), 0, 100, 0, 255);
      analogWrite(in13, 0);
      analogWrite(in14, frrSpeed);
    }
    if (motNum == 3) {
      blSpeed = map(inputString.toInt(), 0, 100, 0, 255);
      analogWrite(in21, blSpeed);
      analogWrite(in22, 0);
    }
    else if (motNum == 31) {
      blrSpeed = map(inputString.toInt(), 0, 100, 0, 255);
      analogWrite(in21, 0);
      analogWrite(in22, blrSpeed);
    }
    if (motNum == 4) {
      brSpeed = map(inputString.toInt(), 0, 100, 0, 255);
      analogWrite(in23, brSpeed);
      analogWrite(in24, 0);
    }
    else if (motNum == 41) {
      brrSpeed = map(inputString.toInt(), 0, 100, 0, 255);
      analogWrite(in23, 0);
      analogWrite(in24, brrSpeed);
    }
    if (motNum == 0) {
      analogWrite(in11, 0);
      analogWrite(in12, 0);
      analogWrite(in13, 0);
      analogWrite(in14, 0);
      analogWrite(in21, 0);
      analogWrite(in22, 0);
      analogWrite(in23, 0);
      analogWrite(in24, 0);
    }

    inputString = "";
    //Add lines to clear xSpeed here if value retention not wanted
    stringComplete = false;
  }
  
  //serialOutput(); // remove comments when ToF installed
}

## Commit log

2018-06-09 added directional motor movement skeleton code
    moved circularRound() to new lib.py library
    refactoring a bit
2018-06-09 added compass, refactoring of motors
2018-06-14 Update calibration
2018-08-06 added motor comm to arduino
2018-08-07 Fix define int syntax
    [arduino.ino]
2018-08-08 Add specific wheel direction code (CW or ACW movement)
2018-08-08 Include serial library, serial code; Add variables for separate sensor data
2018-08-09 Optimise code, add ability for 4 ToF sensors
2018-08-11 Add momentary switch ball detection with debouncing
2018-08-11 Add momentary switch differentiation, remove ToF commentation
2018-08-13 Fix SetID and momentary switch
    [arduino.ino]
2018-08-13 Create motortest_origmethod.ino (known to work method)
2018-08-13 Fix serial input realisation, use new method for spin direction
    [arduino.ino]
2018-08-13 reversed motor output syntax
    [compass.py]
2018-08-13 Fix serial motor power realisation
    [arduino.ino]
2018-08-13 Fix specific motor addressing
    [arduino.ino]
2018-08-13 Remove momentary switch code
2018-08-13 sensors on pi
2018-08-13 Comment out debug serial prints
2018-08-15 Add power switch and other
2018-08-16 New motor code
2018-08-16 Add schematic component availability checkboxes
2018-09-06 lighting-agnostic calibration hopefully
2018-09-06 added ball location, auto calibration (pretty much good to go)
2018-09-06 added getBallCenter() function, gets ball location relative to the center of the camera - uses frameDimensions to get camera frame size
2018-09-07 fixed yellow showing up too, also removed blurring to increase speed
    [main.py]
2018-09-11 Added on/off switch
2018-09-13 Added led control
2018-09-13 Added short term maxVal memory
    [vision.py]
2018-09-20 No longer detects the goal - EZ MONEY
    [main.py, stubs.py, vision.py]
2018-09-25 Add calibrated code with calibration matrix and bias
2018-09-25 Add calibration matrices
2018-09-25 updated vision threading
2018-09-25 removed deprecated material -- can find in version control / history
2018-09-26 increased reliability, replaced currentBallCenter with relativeBallCenter in vp.read(), edited readme
    [vision.py]
2018-09-26 Update main.py to work with threaded vision
2018-09-26 Add note for compass calibration data
2018-09-26 DXF moved
    Top and Mid plate dxf files moved to the correct folders.
    [MidPlate.dxf, TopPlate.dxf]
2018-09-26 Test file
    Added test file
    [test.dxf]
2018-09-26 Add new auto calibration code (adapting)
2018-09-28 Added BotPlate.dxf
    Self explanatory I hope.
    [BotPlate.dxf]
2018-09-28 Added STL files
    3D models used in our bots.
    [BatteryMount.stl, CameraMount.stl, InnerMount.stl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]
2018-09-28 Uploaded the originals
    Uploaded fusion and blender files.
    [Bot Visualisation.blend, BotPlate.f3d, Camera Mount.blend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]
2018-09-28 Organised a bit
    [Bot Visualisation.blend, BotPlate.f3d, Camera Mount.blend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]
2018-09-29 Upgrade Compass_Code.ino (calibrated co-ordinates and heading)
    New calculation styles, new calibration method, fresh code
2018-09-29 Fix variable declaration format
    [Compass_Code.ino]
2018-09-30 Updated camera mounts
    [Camera Mount.blend, CameraMount.stl]
2018-10-02 Battery mount stl
    [BatteryMount.stl]
2018-10-04 ROLLER MOUNTTT
    [RollMount.stl]
2018-10-04 ROOLLLL MOUNTTT
    [RollMount.stl]
2018-10-04 DRIB MOT MOUNT
    [DribMotMount.stl]
2018-10-04 roller mounter
    [RollMount.stl]
2018-10-04 print pls
    [RollMount.stl]
2018-10-05 print now pls
    [Motdrib1.stl]
2018-10-05 print this one as welll
    [Motdrib2.stl]
2018-10-05 Replace constant variables with single constants
    Revert to previous version if not working
    [Compass_Code.ino]
